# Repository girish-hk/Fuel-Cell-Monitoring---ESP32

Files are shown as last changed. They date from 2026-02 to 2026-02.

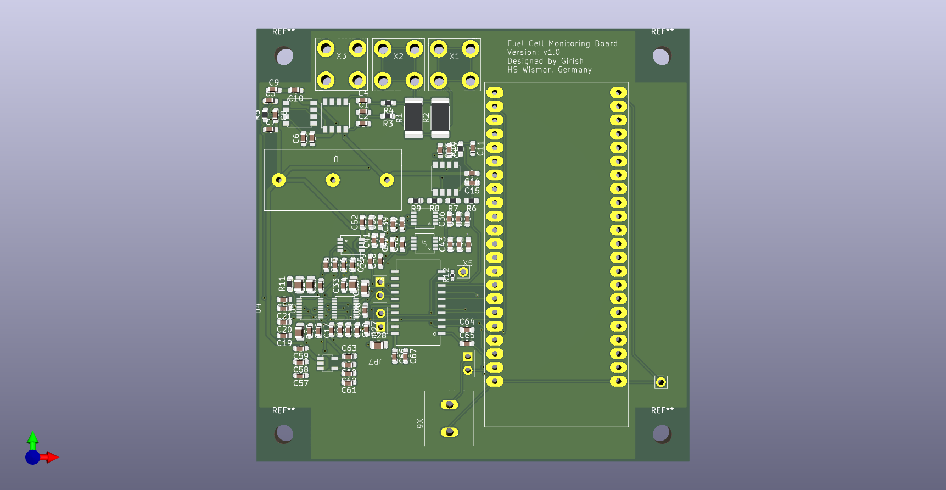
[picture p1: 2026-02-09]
board desing and 3D file/board top view.png

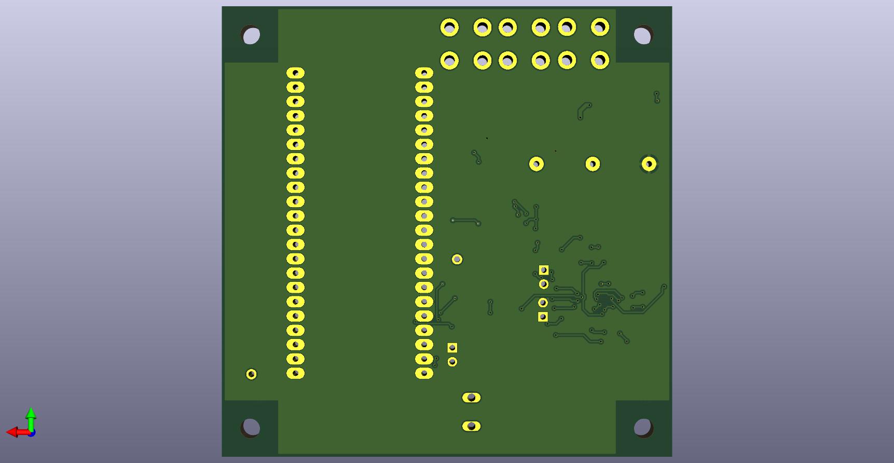
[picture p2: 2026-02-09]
board desing and 3D file/board bottom view.jpg

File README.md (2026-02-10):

# Fuel Cell DAQ PCB – ESP32-S3

This repository contains the hardware design of a **Fuel Cell Monitoring and Measurement Board** developed in KiCad.  
The board is designed to monitor key electrical parameters of a PEM fuel cell system and interface with an **ESP32-S3** microcontroller.

  ## Project Overview
- Application: Fuel Cell Monitoring & Data Acquisition
- Input Voltage Range: 24V – 45V DC
- Microcontroller: ESP32-S3
- PCB Design Tool: KiCad 8

##  Key Design Features
- **High-side current sensing** for accurate measurement
- **Galvanic isolation** between control and measurement domains
- **Low-noise analog signal conditioning**
- PCB verified using **ERC and DRC checks** in KiCad

##  3D Board View

### Top View
Top View

### Bottom View
Bottom View

##  Repository Structure
- `Hardware/` – KiCad schematic and PCB layout files  
- `Libraries/` – Custom symbols and footprints  
- `Production/` – Gerber files and Bill of Materials  
- `Docs/` – Schematic PDF and project documentation  
- `Images/` – 3D rendered views of the PCB  

## Tools Used
- KiCad 8 (Schematic & PCB Design)
- ESP32-S3 platform
- GitHub for version control and documentation

##  Author
**Girish**  
Master’s Student – HS Wismar

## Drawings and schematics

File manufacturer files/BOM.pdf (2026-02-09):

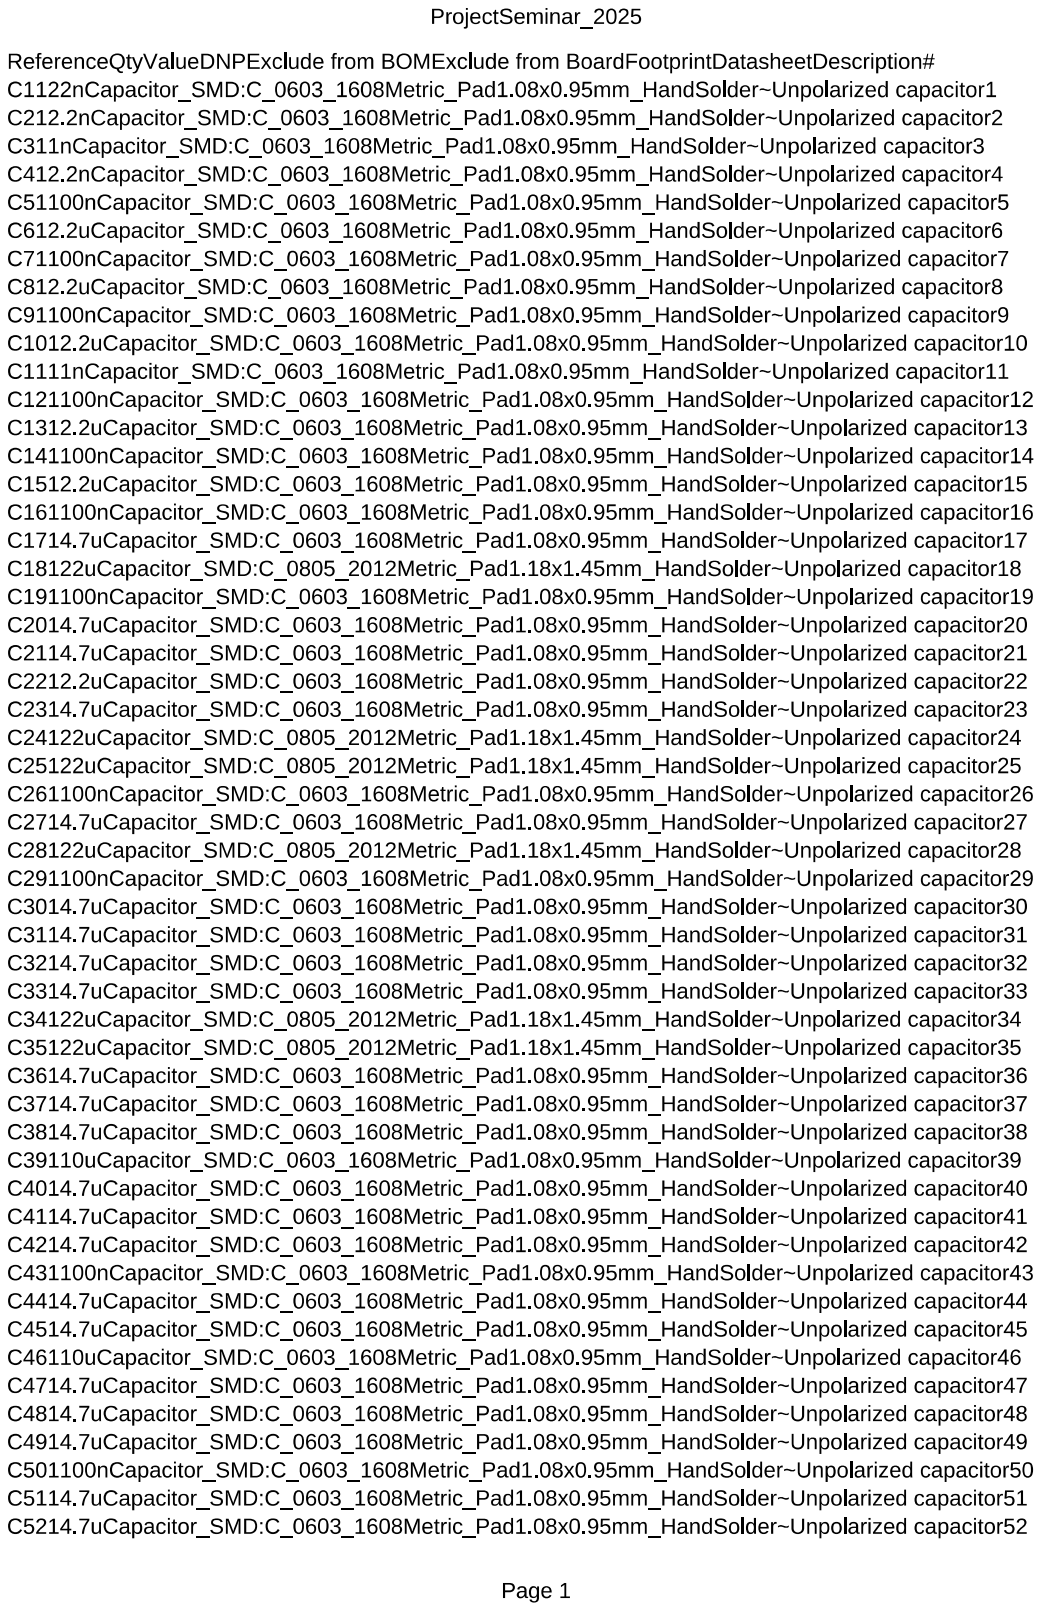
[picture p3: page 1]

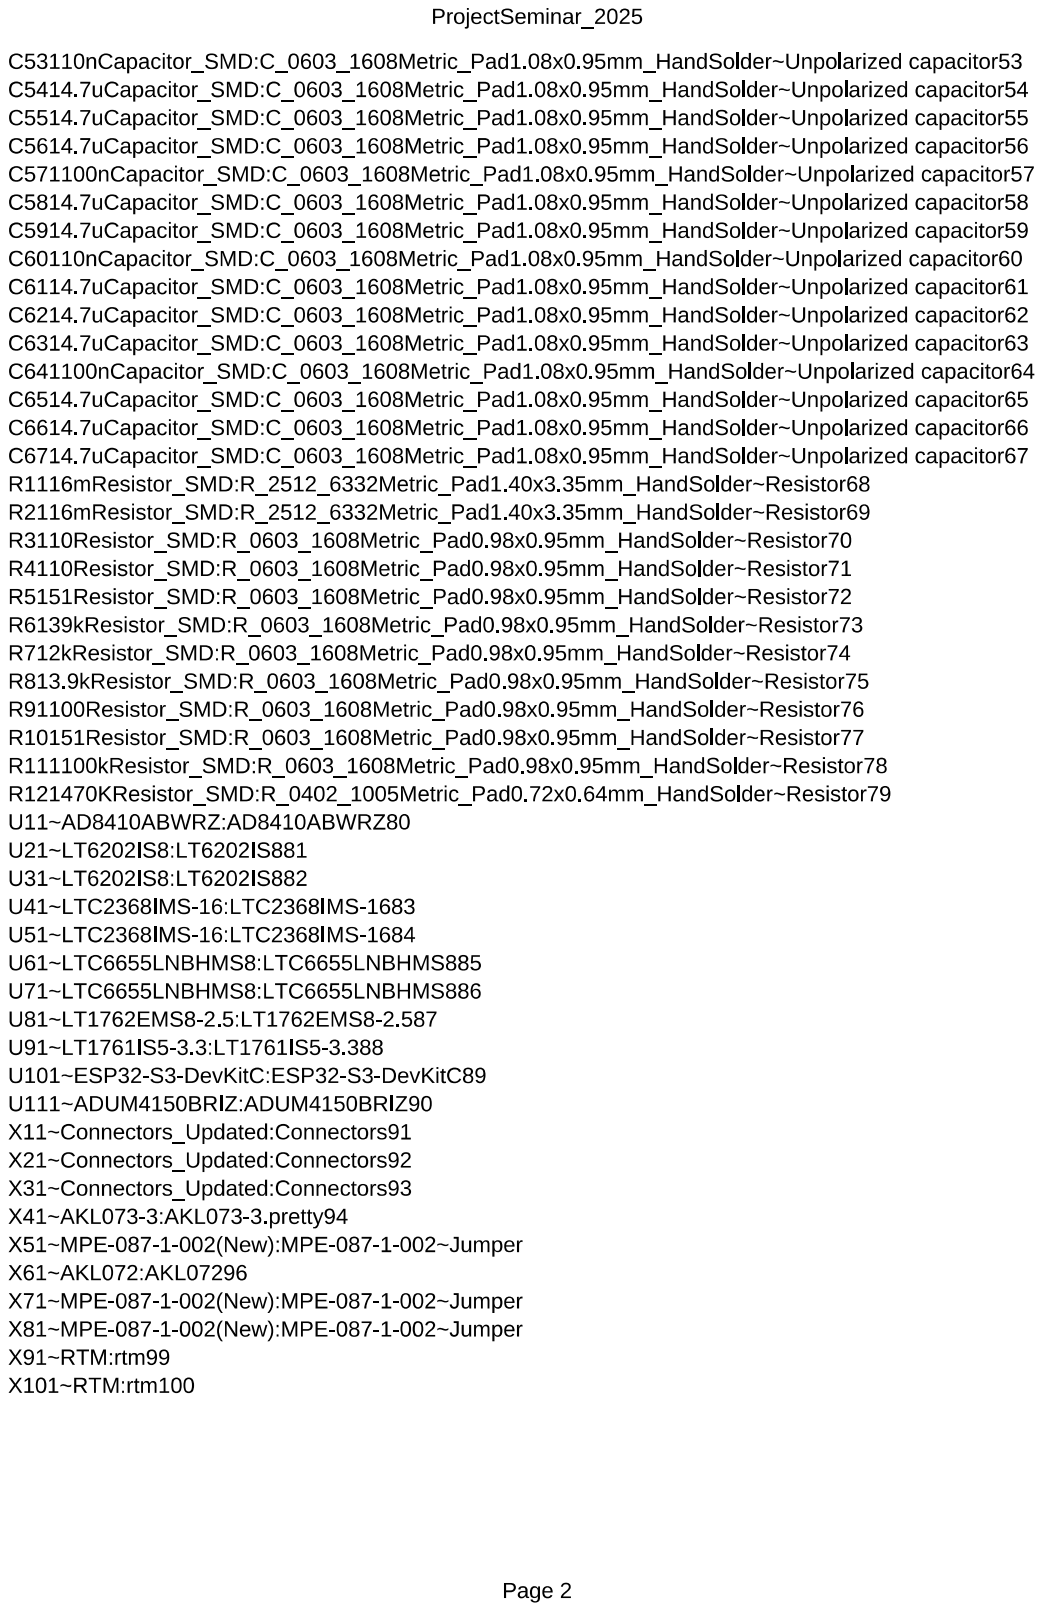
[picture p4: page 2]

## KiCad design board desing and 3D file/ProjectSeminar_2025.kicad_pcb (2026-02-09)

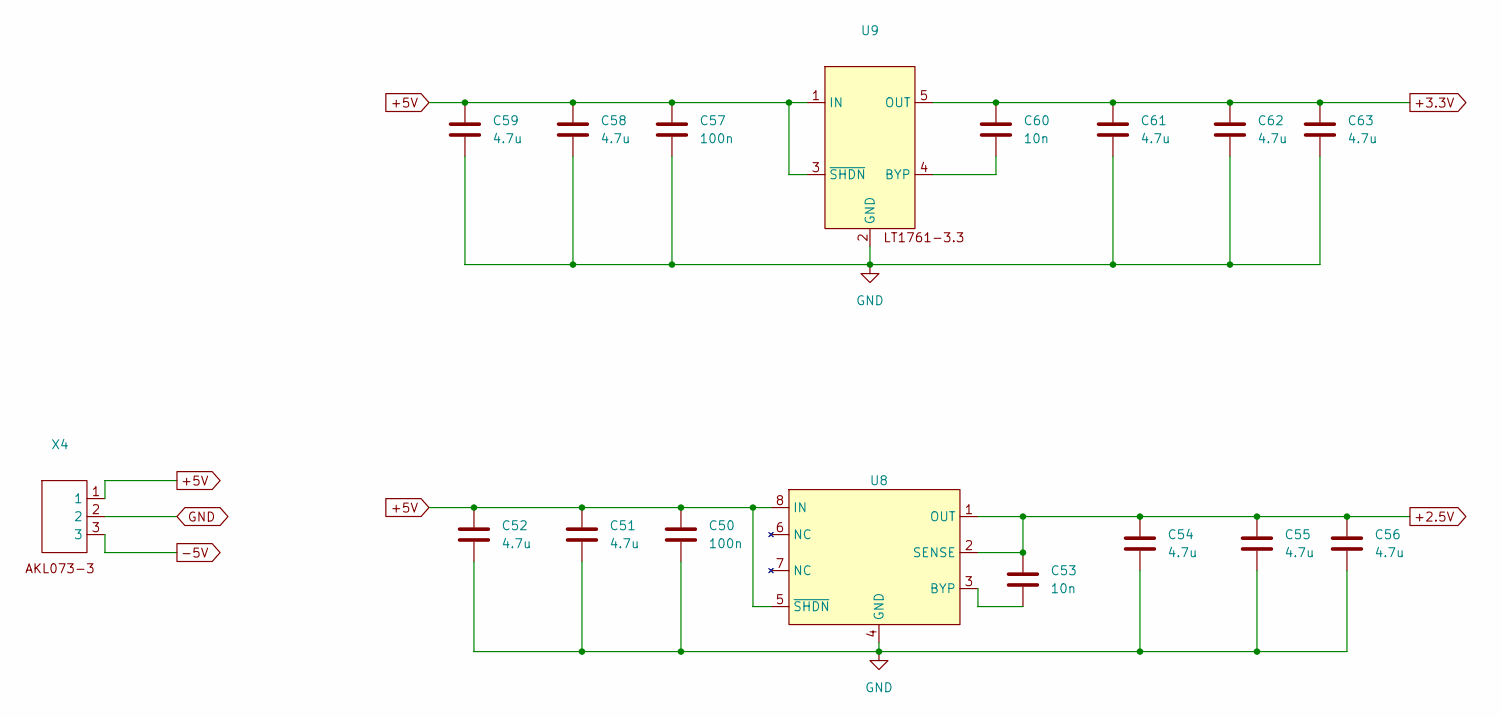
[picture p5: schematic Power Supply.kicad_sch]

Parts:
C50, C57: 100n; C_0603_1608Metric_Pad1.08x0.95mm_HandSolder
C51, C52, C54, C55, C56, C58, C59, C61, C62, C63: 4.7u; C_0603_1608Metric_Pad1.08x0.95mm_HandSolder
C53, C60: 10n; C_0603_1608Metric_Pad1.08x0.95mm_HandSolder
U8: LT1762EMS8-2.5
U9: LT1761IS5-3.3
X4: AKL073-3.pretty

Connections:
+2.5V: C53.1, C54.1, C55.1, C56.1, U8.1 (OUT), U8.2 (SENSE); also elsewhere on the board
+3.3V: C60.1, C61.1, C62.1, C63.1, U9.5 (OUT); also elsewhere on the board
+5V: C50.1, C51.1, C52.1, C57.1, C58.1, C59.1, U8.5 (~SHDN), U8.8 (IN), U9.1 (IN), U9.3 (~SHDN), X4.1; also elsewhere on the board
-5V: X4.3; also elsewhere on the board
GND: C50.2, C51.2, C52.2, C54.2, C55.2, C56.2, C57.2, C58.2, C59.2, C61.2, C62.2, C63.2, U8.4 (GND), U9.2 (GND), X4.2; also elsewhere on the board
unnamed: C53.2, U8.3 (BYP)
unnamed: C60.2, U9.4 (BYP)

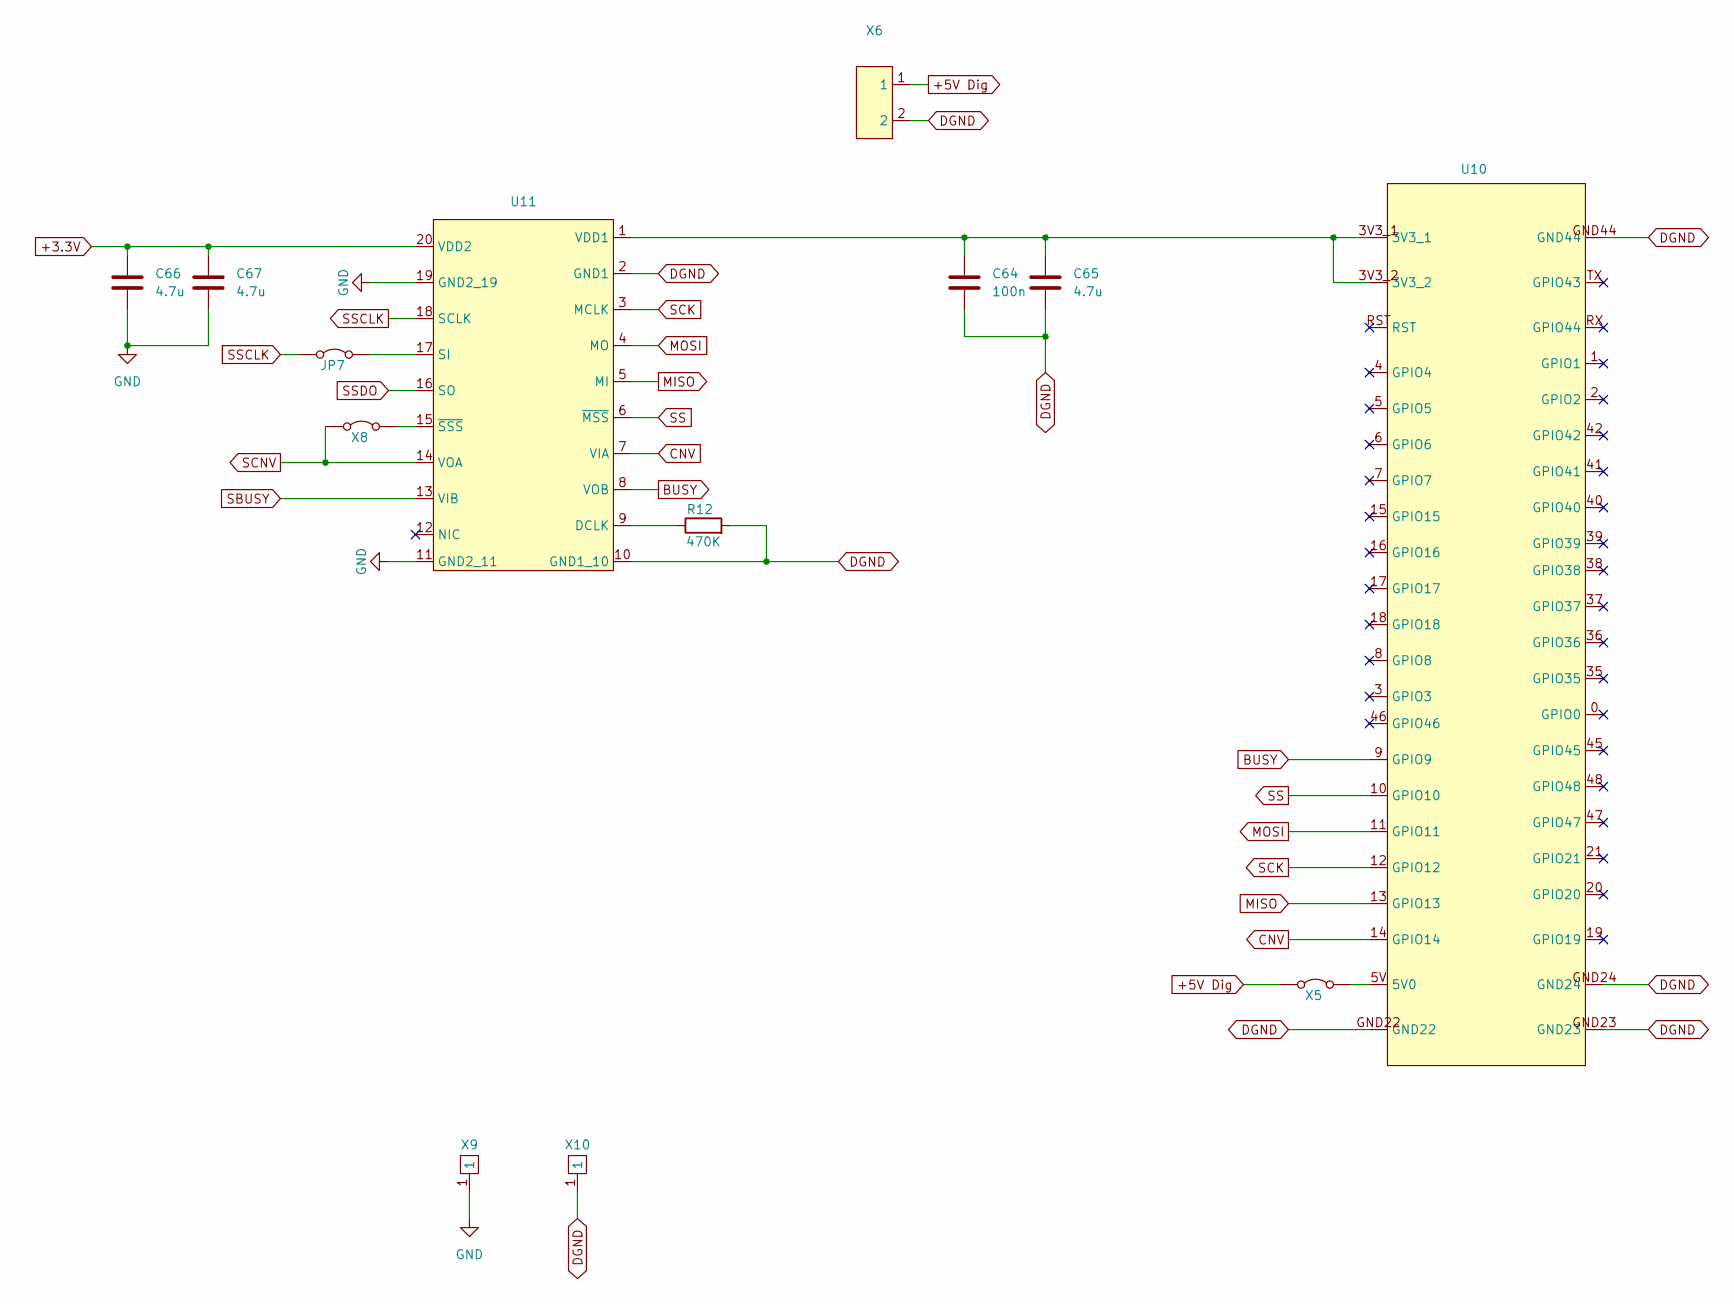
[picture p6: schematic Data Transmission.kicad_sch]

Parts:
C64: 100n; C_0603_1608Metric_Pad1.08x0.95mm_HandSolder
C65, C66, C67: 4.7u; C_0603_1608Metric_Pad1.08x0.95mm_HandSolder
JP7: Jumper_2_Bridged; MPE-087-1-002(1)
R12: 470K; R_0402_1005Metric_Pad0.72x0.64mm_HandSolder
U10: ESP32-S3-DevKitC-1N8; ESP32-S3-DevKitC
U11: ADUM4150BRIZ
X5, X8: MPE-087-1-002(1)
X6: AKL072
X9, X10: rtm

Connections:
+3.3V: C66.1, C67.1, U11.20 (VDD2); also elsewhere on the board
+5V Dig: X5.1 (A), X6.1
BUSY: U10.9 (GPIO9), U11.8 (VOB)
CNV: U10.14 (GPIO14), U11.7 (VIA)
DGND: C64.2, C65.2, R12.2, U10.GND22, U10.GND23, U10.GND24, U10.GND44, U11.2 (GND1), U11.10 (GND1_10), X6.2, X10.1
GND: C66.2, C67.2, U11.11 (GND2_11), U11.19 (GND2_19), X9.1; also elsewhere on the board
MISO: U10.13 (GPIO13), U11.5 (MI)
MOSI: U10.11 (GPIO11), U11.4 (MO)
unnamed: JP7.2 (B), U11.17 (SI)
unnamed: U10.5V (5V0), X5.2 (B)
unnamed: R12.1, U11.9 (DCLK)
unnamed: C64.1, C65.1, U10.3V3_1, U10.3V3_2, U11.1 (VDD1)
unnamed: U11.15 (~SSS), X8.2 (B)
SBUSY: U11.13 (VIB); also elsewhere on the board
SCK: U10.12 (GPIO12), U11.3 (MCLK); also elsewhere on the board
SCNV: U11.14 (VOA), X8.1 (A); also elsewhere on the board
SS: U10.10 (GPIO10), U11.6 (~MSS)
SSCLK: JP7.1 (A), U11.18 (SCLK)
SSDO: U11.16 (SO); also elsewhere on the board

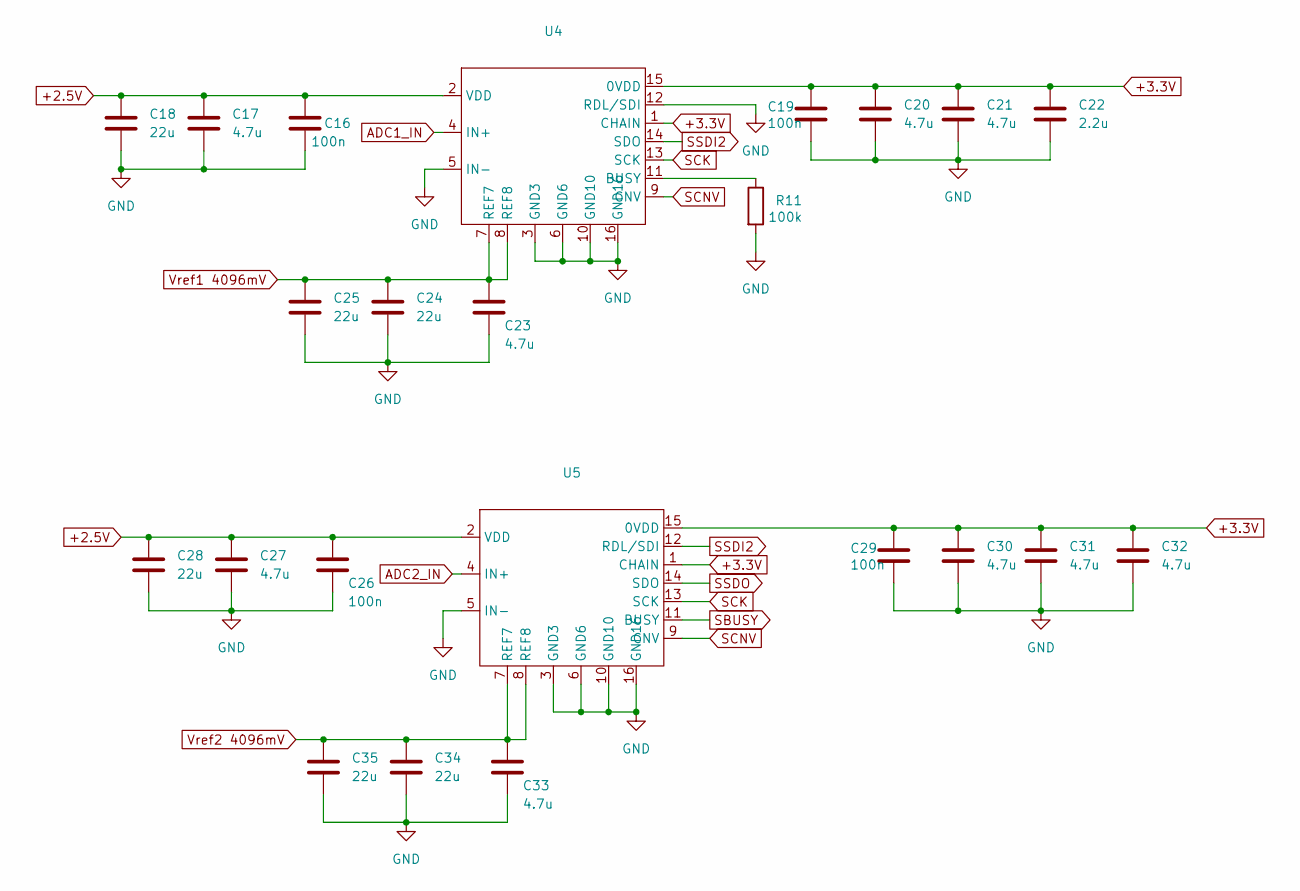
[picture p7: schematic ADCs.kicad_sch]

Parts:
C16, C19, C26, C29: 100n; C_0603_1608Metric_Pad1.08x0.95mm_HandSolder
C17, C20, C21, C23, C27, C30, C31, C32, C33: 4.7u; C_0603_1608Metric_Pad1.08x0.95mm_HandSolder
C18, C24, C25, C28, C34, C35: 22u; C_0805_2012Metric_Pad1.18x1.45mm_HandSolder
C22: 2.2u; C_0603_1608Metric_Pad1.08x0.95mm_HandSolder
R11: 100k; R_0603_1608Metric_Pad0.98x0.95mm_HandSolder
U4, U5: LTC2368IMS-16

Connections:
+2.5V: C16.1, C17.1, C18.1, C26.1, C27.1, C28.1, U4.2 (VDD), U5.2 (VDD); also elsewhere on the board
+3.3V: C19.1, C20.1, C21.1, C22.1, C29.1, C30.1, C31.1, C32.1, U4.1 (CHAIN), U4.15 (0VDD), U5.1 (CHAIN), U5.15 (0VDD); also elsewhere on the board
ADC1_IN: U4.4 (IN+); also elsewhere on the board
ADC2_IN: U5.4 (IN+); also elsewhere on the board
GND: C16.2, C17.2, C18.2, C19.2, C20.2, C21.2, C22.2, C23.2, C24.2, C25.2, C26.2, C27.2, C28.2, C29.2, C30.2, C31.2, C32.2, C33.2, C34.2, C35.2, R11.2, U4.3 (GND3), U4.5 (IN-), U4.6 (GND6), U4.10 (GND10), U4.12 (RDL/SDI), U4.16 (GND16), U5.3 (GND3), U5.5 (IN-), U5.6 (GND6), U5.10 (GND10), U5.16 (GND16); also elsewhere on the board
unnamed: R11.1, U4.11 (BUSY)
SBUSY: U5.11 (BUSY); also elsewhere on the board
SCK: U4.13 (SCK), U5.13 (SCK); also elsewhere on the board
SCNV: U4.9 (CNV), U5.9 (CNV); also elsewhere on the board
SSDI2: U4.14 (SDO), U5.12 (RDL/SDI)
SSDO: U5.14 (SDO); also elsewhere on the board
Vref1 4096mV: C23.1, C24.1, C25.1, U4.7 (REF7), U4.8 (REF8); also elsewhere on the board
Vref2 4096mV: C33.1, C34.1, C35.1, U5.7 (REF7), U5.8 (REF8); also elsewhere on the board

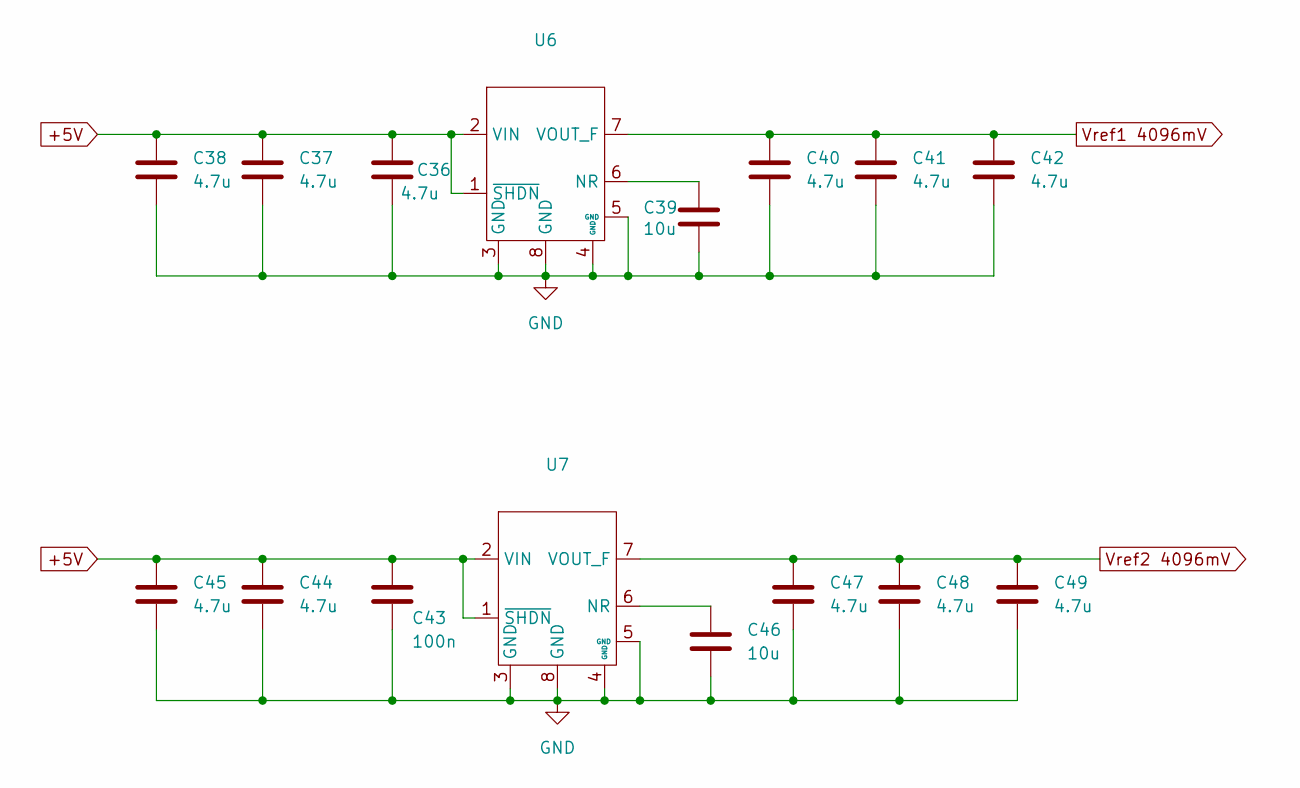
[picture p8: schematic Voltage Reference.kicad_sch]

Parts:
C36, C37, C38, C40, C41, C42, C44, C45, C47, C48, C49: 4.7u; C_0603_1608Metric_Pad1.08x0.95mm_HandSolder
C39, C46: 10u; C_0603_1608Metric_Pad1.08x0.95mm_HandSolder
C43: 100n; C_0603_1608Metric_Pad1.08x0.95mm_HandSolder
U6, U7: LTC6655LNBHMS8

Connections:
+5V: C36.1, C37.1, C38.1, C43.1, C44.1, C45.1, U6.1 (~SHDN), U6.2 (VIN), U7.1 (~SHDN), U7.2 (VIN); also elsewhere on the board
GND: C36.2, C37.2, C38.2, C39.2, C40.2, C41.2, C42.2, C43.2, C44.2, C45.2, C46.2, C47.2, C48.2, C49.2, U6.3 (GND), U6.4 (GND), U6.5 (GND), U6.8 (GND), U7.3 (GND), U7.4 (GND), U7.5 (GND), U7.8 (GND); also elsewhere on the board
unnamed: C39.1, U6.6 (NR)
unnamed: C46.1, U7.6 (NR)
Vref1 4096mV: C40.1, C41.1, C42.1, U6.7 (VOUT_F); also elsewhere on the board
Vref2 4096mV: C47.1, C48.1, C49.1, U7.7 (VOUT_F); also elsewhere on the board

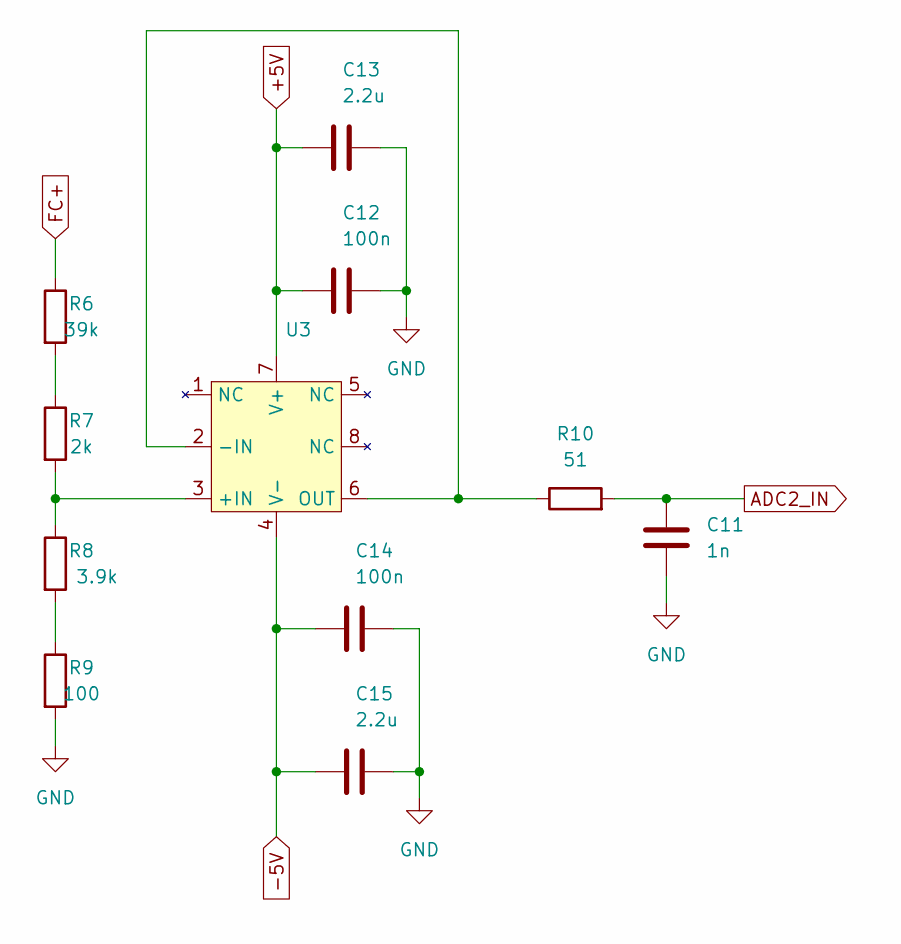
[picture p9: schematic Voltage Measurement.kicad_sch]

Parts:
C11: 1n; C_0603_1608Metric_Pad1.08x0.95mm_HandSolder
C12, C14: 100n; C_0603_1608Metric_Pad1.08x0.95mm_HandSolder
C13, C15: 2.2u; C_0603_1608Metric_Pad1.08x0.95mm_HandSolder
R6: 39k; R_0603_1608Metric_Pad0.98x0.95mm_HandSolder
R7: 2k; R_0603_1608Metric_Pad0.98x0.95mm_HandSolder
R8: 3.9k; R_0603_1608Metric_Pad0.98x0.95mm_HandSolder
R9: 100; R_0603_1608Metric_Pad0.98x0.95mm_HandSolder
R10: 51; R_0603_1608Metric_Pad0.98x0.95mm_HandSolder
U3: LT6202IS8

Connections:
+5V: C12.2, C13.2, U3.7 (V+); also elsewhere on the board
-5V: C14.2, C15.2, U3.4 (V-); also elsewhere on the board
ADC2_IN: C11.1, R10.2; also elsewhere on the board
FC+: R6.1
GND: C11.2, C12.1, C13.1, C14.1, C15.1, R9.2; also elsewhere on the board
unnamed: R6.2, R7.1
unnamed: R8.2, R9.1
unnamed: R7.2, R8.1, U3.3 (+IN)
unnamed: R10.1, U3.2 (-IN), U3.6 (OUT)

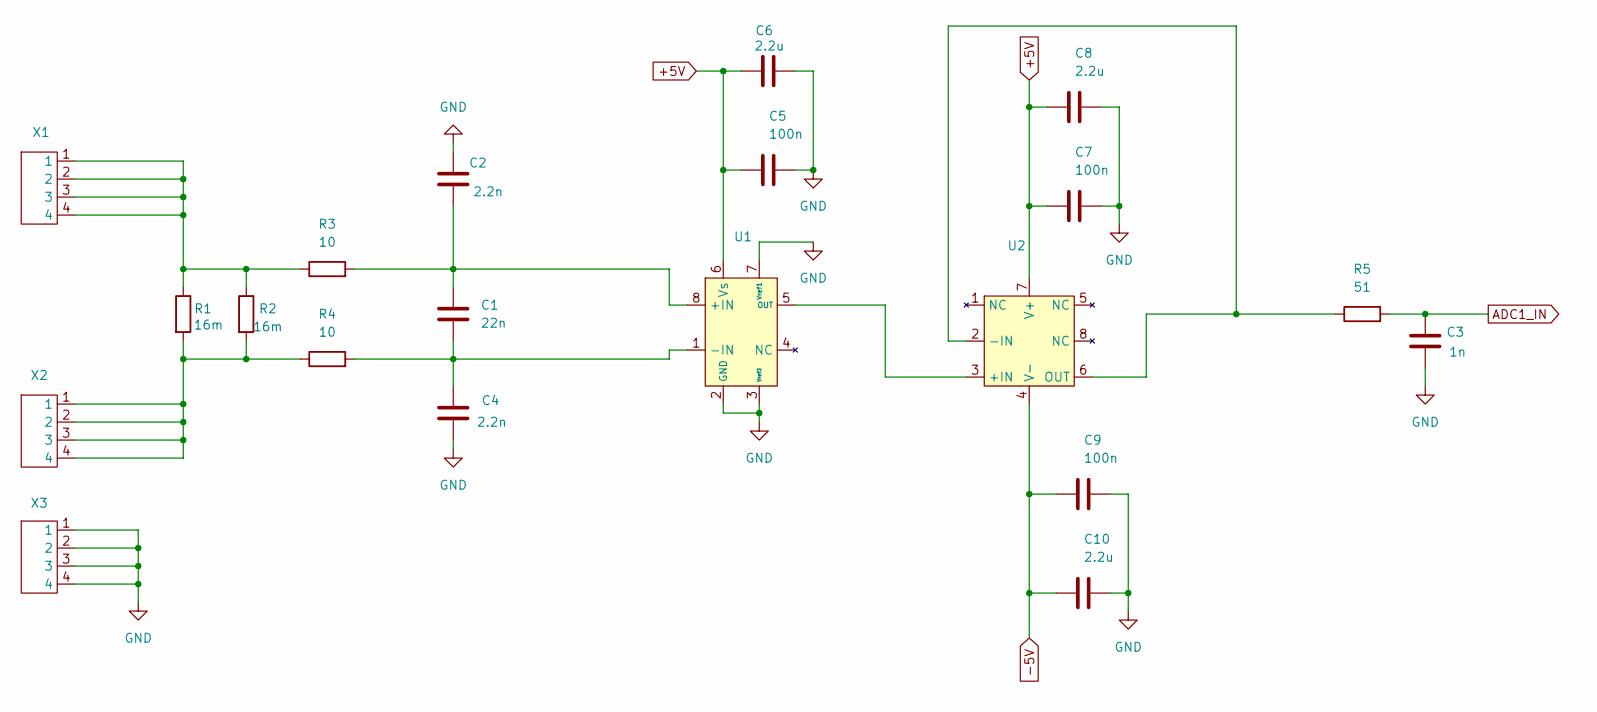
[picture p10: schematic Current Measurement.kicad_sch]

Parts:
C1: 22n; C_0603_1608Metric_Pad1.08x0.95mm_HandSolder
C2, C4: 2.2n; C_0603_1608Metric_Pad1.08x0.95mm_HandSolder
C3: 1n; C_0603_1608Metric_Pad1.08x0.95mm_HandSolder
C5, C7, C9: 100n; C_0603_1608Metric_Pad1.08x0.95mm_HandSolder
C6, C8, C10: 2.2u; C_0603_1608Metric_Pad1.08x0.95mm_HandSolder
R1, R2: 16m; R_2512_6332Metric_Pad1.40x3.35mm_HandSolder
R3, R4: 10; R_0603_1608Metric_Pad0.98x0.95mm_HandSolder
R5: 51; R_0603_1608Metric_Pad0.98x0.95mm_HandSolder
U1: AD8410ABWRZ
U2: LT6202IS8
X1, X2, X3: Connectors

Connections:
+5V: C5.2, C6.2, C7.2, C8.2, U1.6 (Vs), U2.7 (V+); also elsewhere on the board
-5V: C9.2, C10.2, U2.4 (V-); also elsewhere on the board
ADC1_IN: C3.2, R5.2; also elsewhere on the board
GND: C2.2, C3.1, C4.1, C5.1, C6.1, C7.1, C8.1, C9.1, C10.1, U1.2 (GND), U1.3 (Vref2), U1.7 (Vref1), X3.1, X3.2, X3.3, X3.4; also elsewhere on the board
unnamed: R1.1, R2.1, R3.1, X1.1, X1.2, X1.3, X1.4
unnamed: R1.2, R2.2, R4.1, X2.1, X2.2, X2.3, X2.4
unnamed: C1.1, C2.1, R3.2, U1.8 (+IN)
unnamed: C1.2, C4.2, R4.2, U1.1 (-IN)
unnamed: U1.5 (OUT), U2.3 (+IN)
unnamed: R5.1, U2.2 (-IN), U2.6 (OUT)

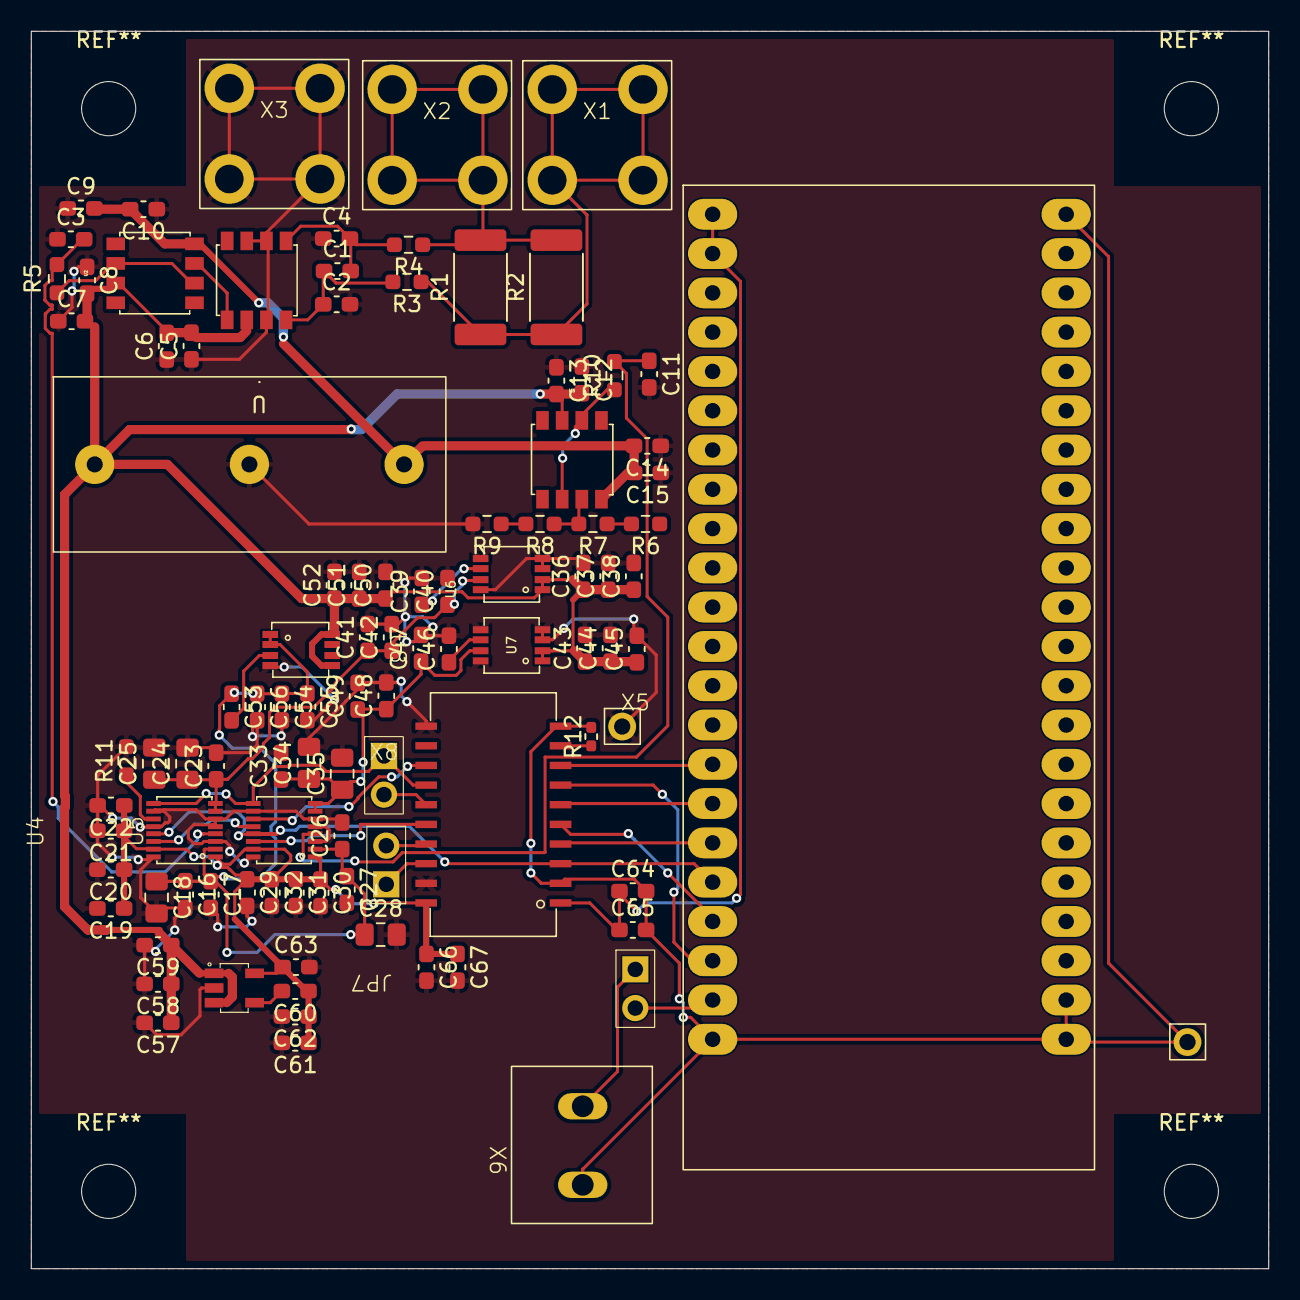
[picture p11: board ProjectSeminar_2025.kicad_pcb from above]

Board: 2 copper layers, 80.0 x 80.0 mm, 100 parts (0 on the bottom side), 42 nets.
